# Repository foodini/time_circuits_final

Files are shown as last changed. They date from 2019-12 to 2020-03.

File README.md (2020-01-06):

# Arduino Time Circuits

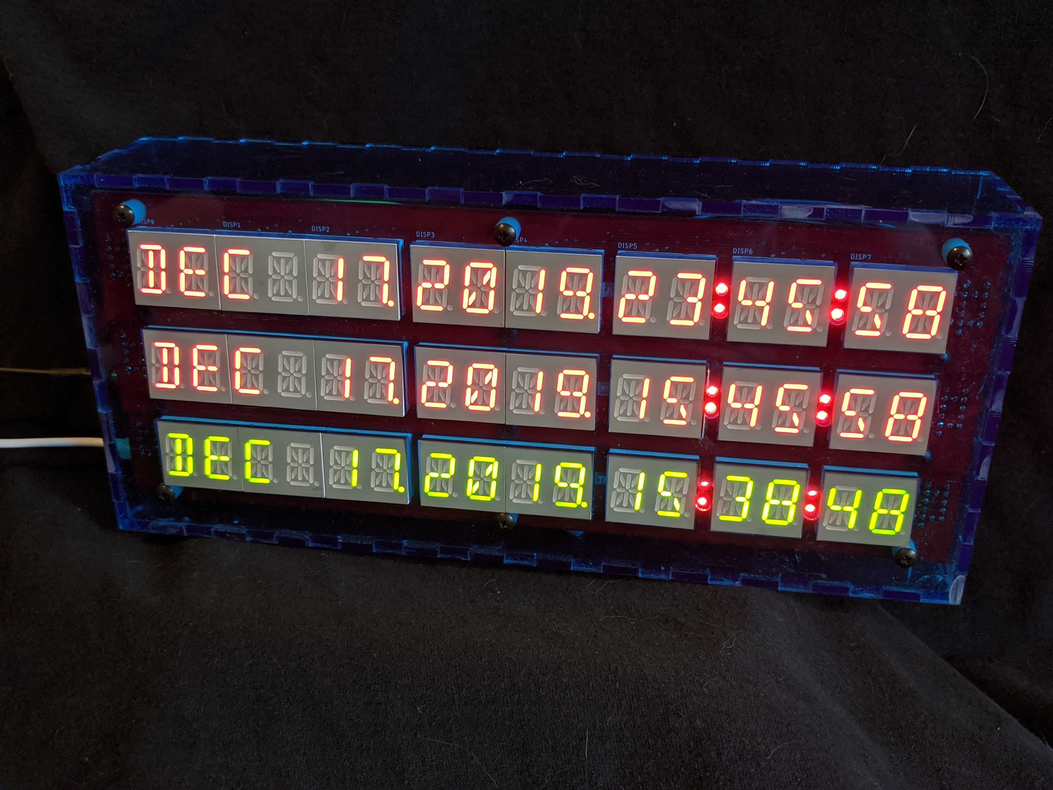
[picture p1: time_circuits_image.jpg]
Time Circuits Image


This is a project I've been working on for.... far too long. There've been [previous iterations]
(https://www.youtube.com/watch?v=cxGm47E_y9M) of this doodad, but [there were issues].
(https://www.youtube.com/watch?v=KKTgsbm41c8)

There was certainly an inspiration from the Back to Future series, but the idea of building a
replica of the device in that series bored me. I like clocks, but I like FUNCTIONAL devices, and
"Where you are, where you're going, and where you've been" isn't very functional to anyone who
hasn't built themselves a real time machine.

What IS useful is a real clock. I frequently work with servers that run on Universal Coordinated
Time (UTC), so having a clock that displays UTC and local time is useful to me. As long as I was
building a two-line clock.... why not three? ("...do it with a little style!") The question of
what to put on the third line languished for a while until it dawned on me what you'd see in a 
clock showing SOLAR time while DRIVING.

Think of it this way: If it takes you ten hours to drive East to the next time zone, it'll be
ELEVEN hours later when you get there. Normally, you just reset your watch when you get there,
but what if we instead had a clock that tracked "Wild West" time. Before time standards, everyone
set their clocks to local noon - they'd use the moment that the sun was highest in the sky as
their standard of time. Why bother? Well, if I'm driving east at about 100kph (at my latitude),
solar time advances by 1.1 times faster than real-time. You can see this difference if you watch
the clock while moving. (Please don't do this if you're the one driving. Duh.)

This clock computes your local solar time every 100ms, taking into account your longitudinal
position, as well as the Earth's position in its orbit. In writing the firmware, I was shocked
to learn that the effect of the orbit on local solar noon varies by something like +- 15 minutes
through the year!
There are still some debug modes languishing in the firmware that should be polished a bit. I'm
sure people will want more features, and I'll do my best to oblige. What I will absolutely NOT
do is make the adjustment for time zones automatic. I did the legwork to make this happen and
came to the conclusion that it simply isn't realistic without giving the clock an SD card and a
way to constantly update its time zone database. To be honest, the largest reason to avoid
this step was because I didn't want to maintain that database. (Time zone definitions change all
the time.) The actual arduino-side processing would have been easy.

## Resources

The project consists of an Arduino .ino file, two Eagle CAD circuit board designs (one for the
displays and one for the Arduino/GPS controller). I'll see if I can work out a way to manage the
Fusion 360 model of the box in GitHub, but in the meantime it's just shared [on Autodesk's
servers].(https://a360.co/2rUt2ZP)

## TODO
- I need to figure out what to do with leap seconds. When there are 61 seconds in a minute, I
  have to handle it properly. At the moment, the clock will display the same time (on the local
  and solar lines) for 2 seconds.
- Since I've gotten the thing boxed up, I've occasionally bumped the settings buttons. This
  causes local time to change by 15 minutes. I think we need to require that you hit the
  mode button to get to the time-change state, where you can alter local time. After n
  seconds, it should return to the main display.
- Make the LED test the last of the display modes.
- Add a histogram that tells you the distribution of inter-sentence reports from the GPS.

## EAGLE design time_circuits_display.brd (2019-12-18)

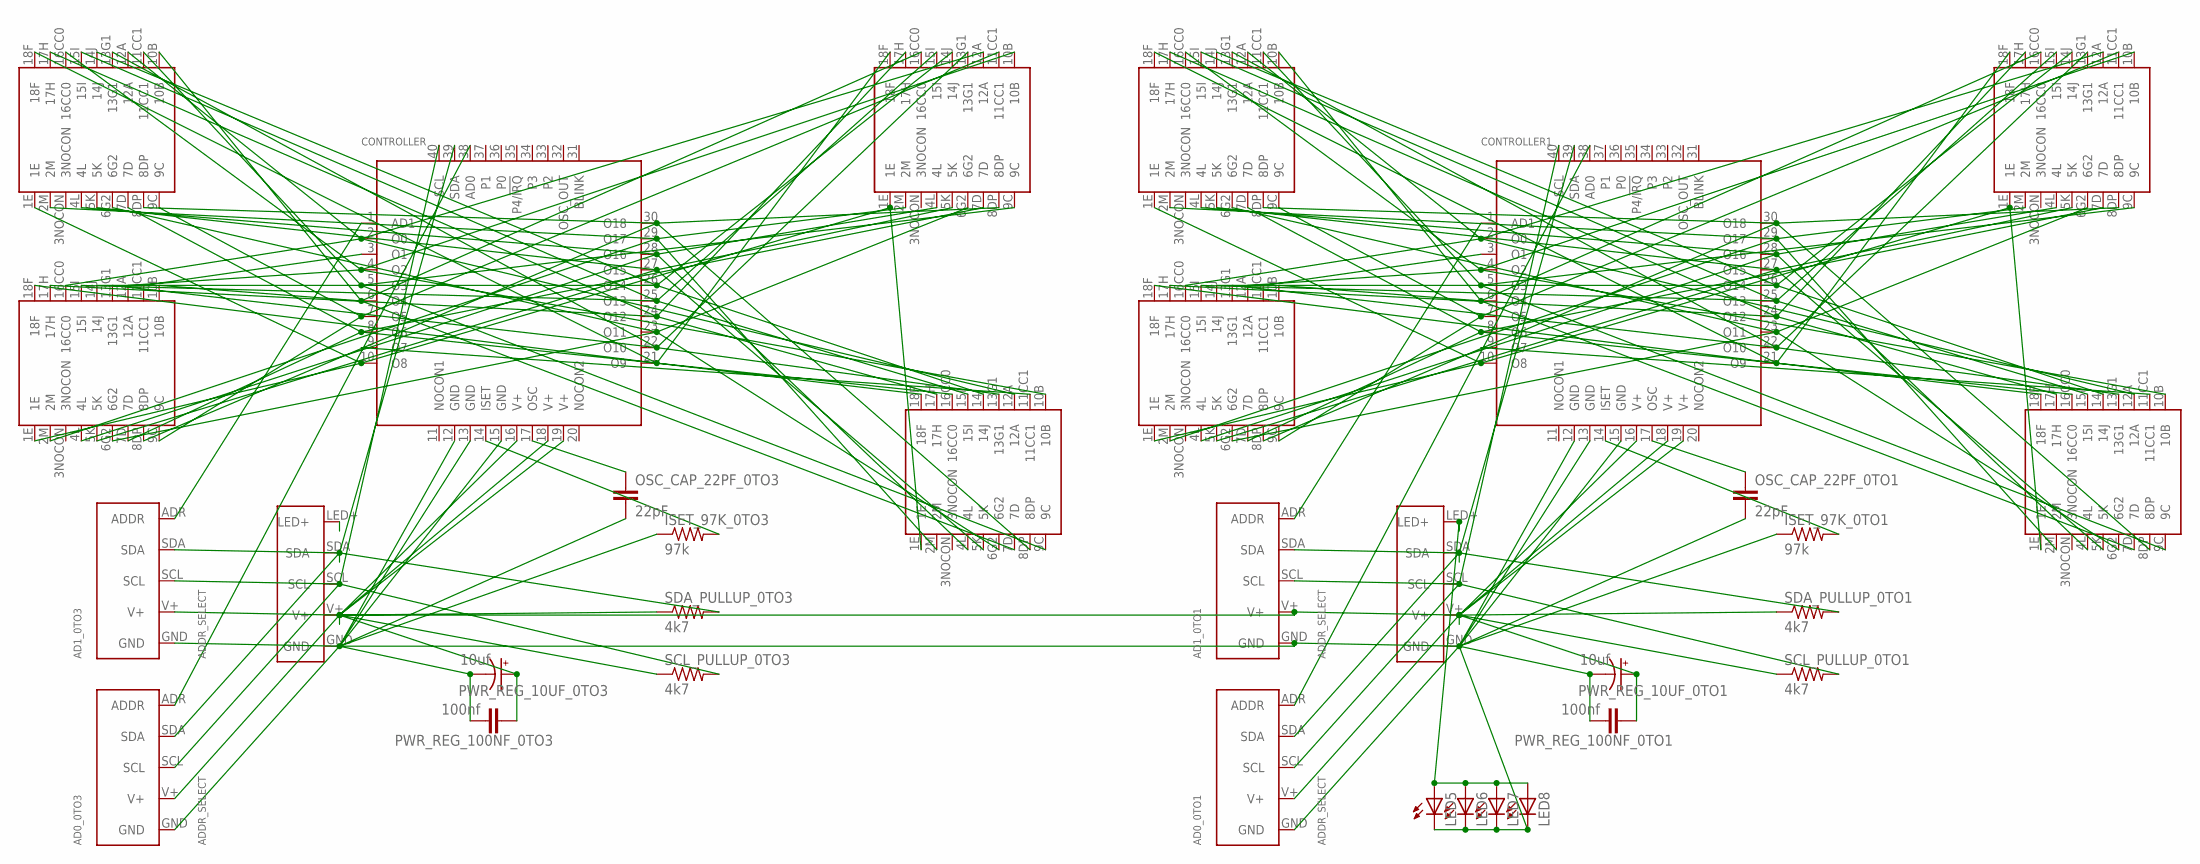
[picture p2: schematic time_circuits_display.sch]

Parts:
AD0_0TO1, AD0_0TO3, AD1_0TO1, AD1_0TO3: ADDR_SELECT
CONTROLLER, CONTROLLER1: MAX6955_TQFN40; TQFN-EP-40
DISP0, DISP1, DISP2, DISP3, DISP4, DISP5, DISP6, DISP7: LTP-3784
GVCD_0TO1, GVCD_0TO3: INTERCONNECTOR4
ISET_97K_0TO1, ISET_97K_0TO3: 97k; 0204/7
LED5, LED6, LED7, LED8: TLLR4400; LED3MM
OSC_CAP_22PF_0TO1, OSC_CAP_22PF_0TO3: 22pF; C025-024X044
PWR_REG_10UF_0TO1, PWR_REG_10UF_0TO3: 10uf; E2-5
PWR_REG_100NF_0TO1, PWR_REG_100NF_0TO3: 100nf; C025-024X044
SCL_PULLUP_0TO1, SCL_PULLUP_0TO3: 4k7; 0204/7
SDA_PULLUP_0TO1, SDA_PULLUP_0TO3: 4k7; 0204/7

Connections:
GND: AD0_0TO1.GND, AD0_0TO3.GND, AD1_0TO1.GND, AD1_0TO3.GND, CONTROLLER.12 (GND), CONTROLLER.13 (GND), CONTROLLER.15 (GND), CONTROLLER1.12 (GND), CONTROLLER1.13 (GND), CONTROLLER1.15 (GND), GVCD_0TO1.GND, GVCD_0TO3.GND, ISET_97K_0TO1.1, ISET_97K_0TO3.1, LED5.K (C), LED6.K (C), LED7.K (C), LED8.K (C), OSC_CAP_22PF_0TO1.2, OSC_CAP_22PF_0TO3.2, PWR_REG_10UF_0TO1.-, PWR_REG_10UF_0TO3.-, PWR_REG_100NF_0TO1.2, PWR_REG_100NF_0TO3.2
unnamed: CONTROLLER.21 (O9), DISP0.18F, DISP1.18F, DISP2.18F, DISP3.18F
unnamed: AD1_0TO3.ADR (ADDR), CONTROLLER.1 (AD1)
unnamed: CONTROLLER.10 (O8), DISP0.1E, DISP1.1E, DISP2.1E, DISP3.1E
unnamed: AD1_0TO1.ADR (ADDR), CONTROLLER1.1 (AD1)
unnamed: CONTROLLER.25 (O13), DISP0.15I, DISP1.15I, DISP2.15I, DISP3.15I
unnamed: AD0_0TO3.ADR (ADDR), CONTROLLER.38 (AD0)
unnamed: CONTROLLER.2 (O0), DISP0.16CC0, DISP1.12A, DISP2.12A, DISP3.12A
unnamed: CONTROLLER.3 (O1), DISP0.11CC1
unnamed: CONTROLLER.4 (O2), DISP0.12A, DISP1.16CC0, DISP2.10B, DISP3.10B
unnamed: CONTROLLER.5 (O3), DISP1.11CC1, DISP2.9C, DISP3.9C
unnamed: CONTROLLER.6 (O4), DISP0.10B, DISP1.10B, DISP2.16CC0, DISP3.7D
unnamed: CONTROLLER.7 (O5), DISP0.9C, DISP1.9C, DISP2.11CC1
unnamed: CONTROLLER.22 (O10), DISP0.13G1, DISP1.13G1, DISP2.13G1, DISP3.13G1
unnamed: CONTROLLER.9 (O7), DISP3.11CC1
unnamed: CONTROLLER.23 (O11), DISP0.6G2, DISP1.6G2, DISP2.6G2, DISP3.6G2
unnamed: CONTROLLER.24 (O12), DISP0.17H, DISP1.17H, DISP2.17H, DISP3.17H
unnamed: CONTROLLER.26 (O14), DISP0.14J, DISP1.14J, DISP2.14J, DISP3.14J
unnamed: CONTROLLER.27 (O15), DISP0.5K, DISP1.5K, DISP2.5K, DISP3.5K
unnamed: CONTROLLER.28 (O16), DISP0.4L, DISP1.4L, DISP2.4L, DISP3.4L
unnamed: CONTROLLER.29 (O17), DISP0.2M, DISP1.2M, DISP2.2M, DISP3.2M
unnamed: CONTROLLER.30 (O18), DISP0.8DP, DISP1.8DP, DISP2.8DP, DISP3.8DP
unnamed: CONTROLLER.17 (OSC), OSC_CAP_22PF_0TO3.1
unnamed: CONTROLLER.14 (ISET), ISET_97K_0TO3.2
unnamed: AD0_0TO3.SCL, AD1_0TO3.SCL, CONTROLLER.40 (SCL), GVCD_0TO3.SCL, SCL_PULLUP_0TO3.2
unnamed: AD0_0TO1.ADR (ADDR), CONTROLLER1.38 (AD0)
unnamed: CONTROLLER.8 (O6), DISP0.7D, DISP1.7D, DISP2.7D, DISP3.16CC0
unnamed: AD0_0TO3.SDA, AD1_0TO3.SDA, CONTROLLER.39 (SDA), GVCD_0TO3.SDA, SDA_PULLUP_0TO3.2
unnamed: CONTROLLER1.2 (O0), DISP4.16CC0, DISP5.12A, DISP6.12A, DISP7.12A
unnamed: CONTROLLER1.3 (O1), DISP4.11CC1
unnamed: CONTROLLER1.4 (O2), DISP4.12A, DISP5.16CC0, DISP6.10B, DISP7.10B
unnamed: CONTROLLER1.5 (O3), DISP5.11CC1, DISP6.9C, DISP7.9C
unnamed: CONTROLLER1.6 (O4), DISP4.10B, DISP5.10B, DISP6.16CC0, DISP7.7D
unnamed: CONTROLLER1.7 (O5), DISP4.9C, DISP5.9C, DISP6.11CC1
unnamed: CONTROLLER1.22 (O10), DISP4.13G1, DISP5.13G1, DISP6.13G1, DISP7.13G1
unnamed: CONTROLLER1.9 (O7), DISP7.11CC1
unnamed: CONTROLLER1.23 (O11), DISP4.6G2, DISP5.6G2, DISP6.6G2, DISP7.6G2
unnamed: CONTROLLER1.24 (O12), DISP4.17H, DISP5.17H, DISP6.17H, DISP7.17H
unnamed: CONTROLLER1.26 (O14), DISP4.14J, DISP5.14J, DISP6.14J, DISP7.14J
unnamed: CONTROLLER1.27 (O15), DISP4.5K, DISP5.5K, DISP6.5K, DISP7.5K
unnamed: CONTROLLER1.28 (O16), DISP4.4L, DISP5.4L, DISP6.4L, DISP7.4L
unnamed: CONTROLLER1.29 (O17), DISP4.2M, DISP5.2M, DISP6.2M, DISP7.2M
unnamed: CONTROLLER1.30 (O18), DISP4.8DP, DISP5.8DP, DISP6.8DP, DISP7.8DP
unnamed: CONTROLLER1.17 (OSC), OSC_CAP_22PF_0TO1.1
unnamed: CONTROLLER1.14 (ISET), ISET_97K_0TO1.2
unnamed: CONTROLLER1.8 (O6), DISP4.7D, DISP5.7D, DISP6.7D, DISP7.16CC0
unnamed: AD0_0TO1.SDA, AD1_0TO1.SDA, CONTROLLER1.39 (SDA), GVCD_0TO1.SDA, SDA_PULLUP_0TO1.2
unnamed: AD0_0TO1.SCL, AD1_0TO1.SCL, CONTROLLER1.40 (SCL), GVCD_0TO1.SCL, SCL_PULLUP_0TO1.2
unnamed: GVCD_0TO1.LED+, LED5.A, LED6.A, LED7.A, LED8.A
unnamed: CONTROLLER1.21 (O9), DISP4.18F, DISP5.18F, DISP6.18F, DISP7.18F
unnamed: CONTROLLER1.10 (O8), DISP4.1E, DISP5.1E, DISP6.1E, DISP7.1E
unnamed: CONTROLLER1.25 (O13), DISP4.15I, DISP5.15I, DISP6.15I, DISP7.15I
VCC: AD0_0TO1.V+, AD0_0TO3.V+, AD1_0TO1.V+, AD1_0TO3.V+, CONTROLLER.16 (V+), CONTROLLER.18 (V+), CONTROLLER.19 (V+), CONTROLLER1.16 (V+), CONTROLLER1.18 (V+), CONTROLLER1.19 (V+), GVCD_0TO1.V+, GVCD_0TO3.V+, PWR_REG_10UF_0TO1.+, PWR_REG_10UF_0TO3.+, PWR_REG_100NF_0TO1.1, PWR_REG_100NF_0TO3.1, SCL_PULLUP_0TO1.1, SCL_PULLUP_0TO3.1, SDA_PULLUP_0TO1.1, SDA_PULLUP_0TO3.1

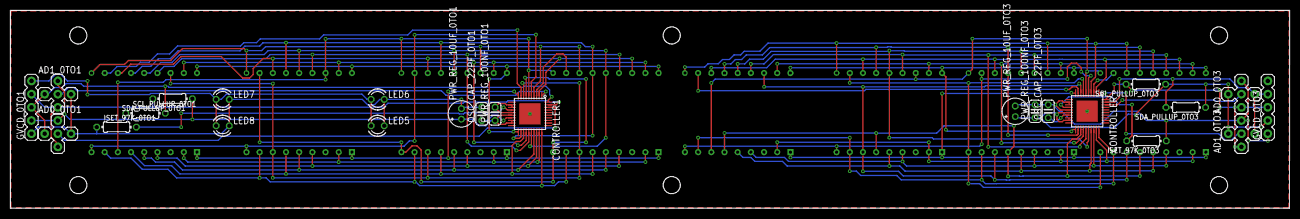
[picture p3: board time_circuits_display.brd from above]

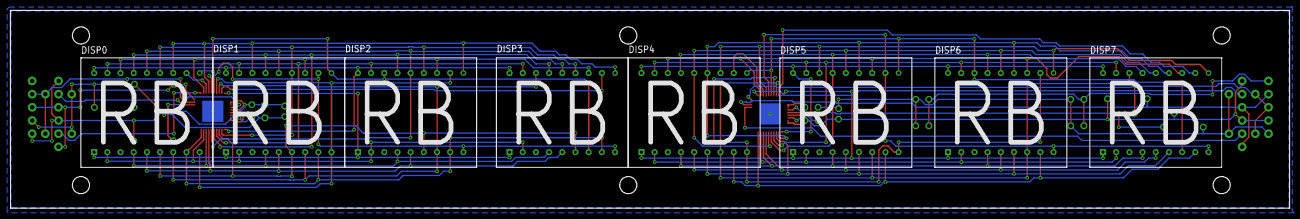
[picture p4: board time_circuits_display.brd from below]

Board: 2 copper layers, 246.4 x 38.1 mm, 32 parts (8 on the bottom side), 53 nets.

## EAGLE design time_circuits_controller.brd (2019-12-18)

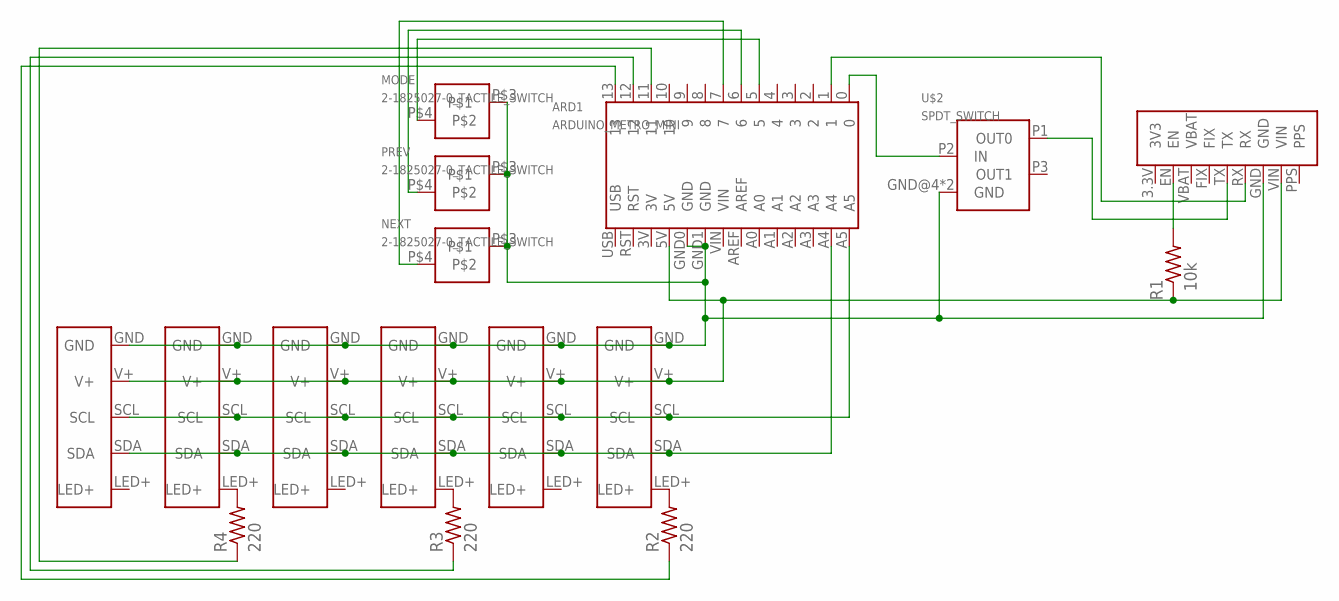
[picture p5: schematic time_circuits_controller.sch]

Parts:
ARD1: ARDUINO_METRO_MINI
MODE: 2-1825027-0_TACTILE_SWITCH
NEXT: 2-1825027-0_TACTILE_SWITCH
OUTPUT_00, OUTPUT_01, OUTPUT_10, OUTPUT_11, OUTPUT_20, OUTPUT_21: INTERCONNECTOR4
PREV: 2-1825027-0_TACTILE_SWITCH
R1: 10k; 0204/7
R2, R3, R4: 220; 0204/7
U$1: GPSBREAKOUTV3
U$2: SPDT_SWITCH

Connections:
5V: ARD1.5V, OUTPUT_00.V+, OUTPUT_01.V+, OUTPUT_10.V+, OUTPUT_11.V+, OUTPUT_20.V+, OUTPUT_21.V+, R1.1, U$1.VIN
GND: ARD1.GND0 (GND), ARD1.GND1 (GND), MODE.P$3, NEXT.P$3, OUTPUT_00.GND, OUTPUT_01.GND, OUTPUT_10.GND, OUTPUT_11.GND, OUTPUT_20.GND, OUTPUT_21.GND, PREV.P$3, U$1.GND, U$2.GND@4 (GND), U$2.GND@5 (GND)
unnamed: R1.2, U$1.EN
unnamed: OUTPUT_21.LED+, R2.2
unnamed: OUTPUT_11.LED+, R3.2
unnamed: ARD1.1, U$1.RX
unnamed: ARD1.5, MODE.P$4
unnamed: ARD1.0, U$2.P2 (IN)
unnamed: ARD1.A5, OUTPUT_00.SCL, OUTPUT_01.SCL, OUTPUT_10.SCL, OUTPUT_11.SCL, OUTPUT_20.SCL, OUTPUT_21.SCL
unnamed: ARD1.A4, OUTPUT_00.SDA, OUTPUT_01.SDA, OUTPUT_10.SDA, OUTPUT_11.SDA, OUTPUT_20.SDA, OUTPUT_21.SDA
unnamed: OUTPUT_01.LED+, R4.2
unnamed: ARD1.11, R4.1
unnamed: ARD1.12, R3.1
unnamed: ARD1.13, R2.1
unnamed: U$1.TX, U$2.P1 (OUT0)
unnamed: ARD1.6, PREV.P$4
unnamed: ARD1.7, NEXT.P$4

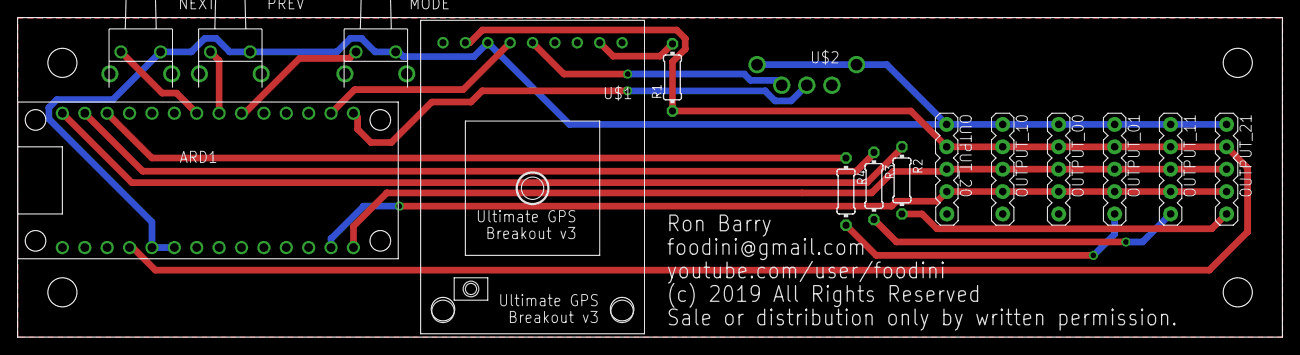
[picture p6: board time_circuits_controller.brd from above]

Board: 2 copper layers, 143.5 x 36.2 mm, 16 parts (0 on the bottom side), 17 nets.

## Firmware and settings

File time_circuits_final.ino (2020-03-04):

#include "Wire.h"

//#include <SoftwareSerial.h>  //Must be here to avoid weird compile error in Adafruit_GPS.h
#include <Adafruit_GPS.h>
#include <EEPROM.h>

#include "tc_datetime.h"
#include "tc_util.h"

/*
 * TODO:
 * 
 *  * There are only 38 actual time zones (https://en.wikipedia.org/wiki/List_of_UTC_time_offsets)
 *  * We have one major problem remaining. The 61st second of leap seconds.
 *  * Break out the EEPROM comms into its own .h/.cpp
 *  * Break out button handling into its own .h/.cpp
 *  * Fix the discontinuity in solar_offset. I wrote it very late at night and never got back.
 *  * Standardize commenting style.
 */

/*
      AD1 AD0 A6 A5 A4 A3 A2 A1 A0
  0   GND GND 1  1  0  0  0  0  0
  1   GND V+  1  1  0  0  0  0  1
  2   GND SDA 1  1  0  0  0  1  0
  3   GND SCL 1  1  0  0  0  1  1
  4   V+  GND 1  1  0  0  1  0  0
  5   V+  V+  1  1  0  0  1  0  1
  6   V+  SDA 1  1  0  0  1  1  0
  7   V+  SCL 1  1  0  0  1  1  1
  8   SDA GND 1  1  0  1  0  0  0
  9   SDA V+  1  1  0  1  0  0  1
  10  SDA SDA 1  1  0  1  0  1  0
  11  SDA SCL 1  1  0  1  0  1  1
  12  SCL GND 1  1  0  1  1  0  0
  13  SCL V+  1  1  0  1  1  0  1
  14  SCL SDA 1  1  0  1  1  1  0
  15  SCL SCL 1  1  0  1  1  1  1
*/

class Stopwatch {
  private:
    unsigned long m_start_time;
  public:
    Stopwatch() {
      reset();
    }
    void reset() {
      m_start_time = millis();
    }
    unsigned long elapsed() {
      unsigned long cur_time = millis();
      if (cur_time < m_start_time)
        return 4294967295 - m_start_time + cur_time;
      return cur_time - m_start_time;
    }
};

#define NUM_ROWS 3
uint8_t addresses[NUM_ROWS][2] = {
  {B1100000, B1100001},
  {B1100010, B1100011},
  {B1100100, B1100101},
};

Adafruit_GPS GPS(&Serial);
bool connected_to_gps = false;
SIGNAL(TIMER0_COMPA_vect) {
  char c = GPS.read();
}

// The vast majority of the time, I populate the frame buffer and immediately push its state
// out to the display. It's nice to have it, though, because it means that I can write stuff
// to it during debugging and expect it to display on the next push.
char display_strs[NUM_ROWS][16];

// display states;
//   0  standard time display
//   1  GPS location display
//   2  debug stats
//   3  Turn on all LEDs
//   4  # loop() runs, time since last GPS fix, millis(), millis()@last GPS receipt
//   5  debugging info for lost GPS comms
//   6  EEPROM state for local timezone offset storage.
uint8_t display_state;

// Button states. Each "down" state is set while the button is held down. "pressed"
// is only true when the button went down on the last refresh.
bool prev_down = false;
bool prev_pressed = false;
bool next_down = false;
bool next_pressed = false;
bool mode_down = false;
bool mode_pressed = false;

uint32_t loops = 0;
uint8_t current_tz_offset;

uint32_t sentences_received = 0;
uint32_t first_sentence_timestamp_ms = 0;

// Pressing the "mode" button switches between a number of displays.
const int8_t NUM_MODES = 6;
bool recent_tz_change = false;

Stopwatch tz_change_timer;

int writeMAX6955(char command, char data, uint8_t address)
{
  Wire.beginTransmission(address);
  Wire.write(command);
  Wire.write(data);
  int error = Wire.endTransmission();
}

#define max6955_reg_decodeMode      0x01
#define max6955_reg_globalIntensity 0x02
#define max6955_reg_scanLimit       0x03
#define max6955_reg_configuration   0x04
#define max6955_reg_displayTest     0x07
#define max6955_reg_digitType       0x0C
void initMAX6955()
{
  Wire.begin();
  for (int row = 0; row < NUM_ROWS; row++) {
    for (int controller = 0; controller < 2; controller++) {
      uint8_t address = addresses[row][controller];
      // ascii decoding for all digits;
      writeMAX6955(max6955_reg_decodeMode, 0xFF, address);
      // brightness: 0x00 =  1/16 (min on)  2.5 mA/seg;
      // 0x0F = 15/16 (max on) 37.5 mA/segment
      writeMAX6955(max6955_reg_globalIntensity, 0x0f, address);
      // active displays: 0x07 -> all;
      writeMAX6955(max6955_reg_scanLimit, 0x07, address);
      // set normal operation;
      writeMAX6955(max6955_reg_configuration, 0x01, address);
      // segments/display: 0xFF=14-seg; 0=16 or 7-seg;
      writeMAX6955(max6955_reg_digitType, 0xff, address);
      // display test on;
      writeMAX6955(max6955_reg_displayTest, 0x01, address);
    }
  }
  delay(1000);
  for (int row = 0; row < NUM_ROWS; row++) {
    for (int controller = 0; controller < 2; controller++) {
      uint8_t address = addresses[row][controller];
      // display test off;
      writeMAX6955(max6955_reg_displayTest, 0x00, address);
      memset(display_strs[0], ' ', 8);
      writeDisplay(display_strs[0], address);
    }
  }
}

void writeDisplay(char* msg, uint8_t address)
{
  for (int i = 0; i < 8; i++)
  {
    writeMAX6955(0x20 + i, msg[i], address);
  }
}

void writeRow(uint8_t row, char * write_str) {
  writeDisplay(write_str, addresses[row][0]);
  writeDisplay(write_str + 8, addresses[row][1]);
}

/*
void writeChar(byte pos, char letter, boolean dotLit, uint8_t address)
{
  writeMAX6955(0x20 + pos, (dotLit ? 0x80 : 0) | letter, address);
}
*/

bool receive_and_parse() {
  if (GPS.newNMEAreceived()) {
    connected_to_gps = true;
    GPS.parse(GPS.lastNMEA());
    return true;
  }
  return false;
}

void stall(int t, char c0, char c1, uint8_t row) {
  int frac = (t + 31) / 32;
  Stopwatch sw;
  char chars[2] = {c0, c1};
  for(int c = 0; c < 2; c++) {
    for(int i = 0; i < 16; i++) {
      sw.reset();
      while (sw.elapsed() < frac) {
        receive_and_parse();
      }
      display_strs[row][i] = chars[c];
      writeRow(row, display_strs[row]);
    }
  }
}

// strcpy, but no '\0' is written to the destination.
void initGPS() {
  OCR0A = 0xAF;
  TIMSK0 |= _BV(OCIE0A);

  // Give the GPS a few milliseconds to start up, in case it's slower than the arduino.
  bare_strcpy(display_strs[0], (char *)"Flux Cap Fluxing");
  writeRow(0, display_strs[0]);
  stall(500, '-', ' ', 1);

  // The GPS receiver defaults to 9600. We want to run it faster, but have to start at 9600
  // to tell it so.
  Serial.begin(9600);
  memset(display_strs[0]+10, ' ', 6);
  bare_strcpy(display_strs[0], (char *)" 9600 baud");
  writeRow(0, display_strs[0]);
  stall(1000, '-',  ' ', 1);

  GPS.sendCommand(PMTK_SET_BAUD_57600);
  memset(display_strs[0]+10, ' ', 6);
  bare_strcpy(display_strs[0], (char *)"57600 baud");
  writeRow(0, display_strs[0]);
  stall(1000, '-',  ' ', 1);

  memset(display_strs[0]+10, ' ', 6);
  bare_strcpy(display_strs[0], (char *)"wait 4 fix");
  writeRow(0, display_strs[0]);
  while(!connected_to_gps || !GPS.fix) {
    Serial.begin(57600);
    if(connected_to_gps) {
      bare_strcpy(display_strs[2], (char *)"Connected to GPS");
      writeRow(2, display_strs[2]);     
    } else if(millis() > 10.0) {
      bare_strcpy(display_strs[2], (char *)"Rear switch on? ");
      writeRow(2, display_strs[2]);
    }
    stall(500, '=',  ' ', 1);
    GPS.sendCommand(PMTK_SET_BAUD_57600);
    GPS.sendCommand(PMTK_SET_NMEA_OUTPUT_RMCONLY);
    GPS.sendCommand(PMTK_SET_NMEA_UPDATE_10HZ);
    stall(2000, '-',  ' ', 1);
  }
}
const uint8_t magic = 0x88;
uint8_t get_eeprom_tz_offset() {
  //Magic number check:
  if(EEPROM.read(510) == magic && EEPROM.read(511) == magic) {
    uint8_t addr = EEPROM.read(509);
    return(EEPROM.read(addr+1)); 
  } else {
    EEPROM.write(510, magic);
    EEPROM.write(511, magic);
    EEPROM.write(509, 0);     //offset to current tz info
    EEPROM.write(0, 0);       //zeroth write to this address pair.
    // This'll provide a rough guess as to which time zone the user is in, based on their longitude.
    uint8_t tz_offset = map(GPS.longitudeDegrees, -180.0, 180.0, 0, 97);
    // round to the nearest hour, with some bias for the high probability that they're on DST.
    tz_offset = ((tz_offset + 5)/4)*4;
    EEPROM.write(1, tz_offset);
    return tz_offset;
  }
}

// Spread the writes across 256 bytes of eeprom.
void set_eeprom_tz_offset(uint8_t offset) {
  uint8_t addr = EEPROM.read(509);
  uint8_t write_count = EEPROM.read(addr);
  if(write_count == 0xff) {
    addr = (addr + 2) % 256;
  }
  EEPROM.write(addr, write_count + 1);
  EEPROM.write(addr+1, offset);
}

// I understand this formula to be accurate to within 15s.
float solar_offset(const Datetime& current_utc) {
  float n;
  float days_in_year = 365.0;
  switch (current_utc.month) {
    case  1: n =   0; break;
    case  2: n =   31; break;
    case  3: n =   59; break;
    case  4: n =   90; break;
    case  5: n =   120; break;
    case  6: n =   151; break;
    case  7: n =   181; break;
    case  8: n =   212; break;
    case  9: n =   243; break;
    case  10: n =   273; break;
    case  11: n =   304; break;
    case  12: n =   334; break;
  }
  if (current_utc.month > 2 && !current_utc.leap_year()) {
    n += 1;
    days_in_year += 1;
  }
  n += current_utc.day;
  n += current_utc.hour / 24.0;
  n += current_utc.minute / (24.0 * 60.0);
  n += current_utc.seconds / (24.0 * 60.0 * 60.0);
  n += current_utc.milliseconds / (24.0 * 60.0 * 60.0 * 1000.0);
  //
  // DISCONTINUITY! Leap years will have a stutter point. (it's 2:15am. figure it out.)
  //
  float d = 2.0 * 3.141592653 * (n - 81.0) / days_in_year;
  return 9.873 * sin(2 * d) - 7.655 * sin(d + 1.374);
}

bool make_solar_time(const Datetime& current_utc, char * str) {
  // The GPS.longitude_fixed is in tenmillionths of a degree. To scale our longitude to a float:
  // GPS.longitude_fixed / 180.0     Scale to the 0.0-1.0 range
  //                     * 12        hours per hemisphere
  //                     * 3600      seconds per hour
  //                     * 1000      milliseconds per second
  //                     / 10^7      removed the fixed-point scaling.
  //                     = * 0.024   Do the divide first to avoid overflow
  int32_t displacement = GPS.longitude_fixed / 1000;
  displacement *= 24;
  // displacement is now the distance - in milliseconds - from 0 longitude

  // Earth's axial tilt and the eccentricity of its orbit cause the difference between solar noon
  // and mean noon to move around by as much as +- 13 minutes. Get the number of milliseconds of
  // difference between mean solar time and solar time:
  displacement += solar_offset(current_utc) * 60 * 1000;

  Datetime solar_time(current_utc);
  solar_time.milliseconds += displacement;
  solar_time.normalize();
  solar_time.make_time_str(str);
  return solar_time.milliseconds < 500;
}

// TODO: Get off of the float latitude and longitude and switch to using the fixed-point
//       version? I do use fixed, elsewhere.
float degmins_to_decimal(float degmins) {
  //Adafruit_GPS stores latitude and longitude in a format where everything to the left of
  //the decimal point is (degrees * 100) + minutes. Right of the decimal point is fraction
  //of minutes. We have to unpack this format to get an old-fashioned float. They probably
  //did it this way for the sake of getting the best precision out of a float that they
  //could.
  degmins /= 100.0;
  int degs = (int)degmins;
  float fract = degmins - degs;
  return degs + fract * 100.0 / 60.0;
}

void set_colons(int8_t pin, bool state) {
  if (state)
    digitalWrite(pin, HIGH);
  else
    digitalWrite(pin, LOW);
}

// For whatever tz offset the user has selected, we've stored it as a value
// between 0 and 97, inclusive. Convert it to an hour/minute offset. Note that
// a negative offset will return negative minutes. This is useful where we add
// these offsets to GPS hours and minutes before normalizing them.
void get_tz_offset(int8_t * hours, int8_t * minutes) {
  int8_t tz_offset_in_qtr_hours = int8_t(current_tz_offset) - 48;
  *hours = tz_offset_in_qtr_hours / 4;
  *minutes = (tz_offset_in_qtr_hours % 4) * 15;
}

// A low-memory way to print ints right-justified. (sprintf aint cheap in terms of
// CPU or memory. Just including it in your code is a huge progmem hit.)
// TODO: allow caller to choose between space-preamble and 0-preamble. You can't just change
//       the memset to do it. Negatives would come out "00-5" instead of "-005".
void rjust(int32_t val, char * buf, int width) {
  memset(buf, ' ', width);
  char tmp[12];
  ltoa(val, tmp, 10);
  int len = strlen(tmp);
  bare_strcpy(buf + width - len, tmp);
}

// Given the current state of the timezone offset, print it to a display row. For the moment,
// it will only print where the LED colons neatly line up (the last 7 digits) so you ge
// "-12:15:00".
void draw_tz_offset(int8_t row) {
  int8_t time_zone_offset_hours, time_zone_offset_minutes;
  get_tz_offset(&time_zone_offset_hours, &time_zone_offset_minutes);
  rjust(time_zone_offset_hours, display_strs[row]+9, 3);
  rjust(abs(time_zone_offset_minutes), display_strs[row]+12, 2);
  // TODO: have rjust take a bool that fills leading zeroes
  if(time_zone_offset_minutes == 0)
    display_strs[row][12] = '0';
  memset(display_strs[row]+14, '0', 2);
  if(time_zone_offset_hours == 0 && time_zone_offset_minutes < 0)
    display_strs[row][10] = '-';
  set_colons(11 + row, GPS.milliseconds < 500);
}

// The ftoa() stdlib function generates a decimal point as a character, e.g., "12.345".
// We don't have to waste a digit to print the column - we simply set the high bit of
// the charcter preceding the decimal point and the DP will light on that display.
// I can't get rid of the temp buffer and render the temp string in-place because the temp string
// is two characters (a '.' and a '\0') longer than the output. 
void ftoa_msb_decimal(float f, char * buf, int int_chars, int frac_chars) {
  char tmpbuf[18];
  char * tmpbufptr = tmpbuf;
  //render the float to a temporary buffer:
  dtostrf(f, int_chars + frac_chars + 1,  frac_chars, tmpbuf);
  while (*tmpbufptr) {
    if (*tmpbufptr == '.') {
      *(buf - 1) |= 0x80;
      tmpbufptr++;
    } else {
      *buf = *tmpbufptr;
      buf++;
      tmpbufptr++;
    }
  }
}

void setup()
{
#ifdef RUN_TESTS
  Serial.begin(19200);
  Datetime::run_tests();
  Serial.end();
  while(1);
#endif
  initMAX6955();

  initGPS();
  pinMode(11, OUTPUT);
  pinMode(12, OUTPUT);
  pinMode(13, OUTPUT);
  pinMode(5, INPUT_PULLUP);
  pinMode(6, INPUT_PULLUP);
  pinMode(7, INPUT_PULLUP);
  display_state = 0;

  current_tz_offset = get_eeprom_tz_offset();

}

void update_button(bool * down, bool * pressed, int pin) {
  *pressed = false;
  if (!digitalRead(pin)) { // if the button is down
    if (!(*down)) { // if it was up
      *pressed = true;
    }
    *down = true;
  } else {
    *down = false;
  }
}

Stopwatch button_repeat_timer;
void update_buttons(const Datetime& current_utc, bool gps_out) {
  bool hold_time_elapsed = false;
  update_button(&prev_down, &prev_pressed, 7);
  update_button(&next_down, &next_pressed, 6);
  update_button(&mode_down, &mode_pressed, 5);

  if(mode_pressed || prev_pressed || next_pressed) {
    button_repeat_timer.reset();
  } else if(button_repeat_timer.elapsed() > 200) {
    button_repeat_timer.reset();
    hold_time_elapsed = true;
  }
  if(mode_pressed || (hold_time_elapsed && mode_down)) {
    display_state = (display_state + 1) % NUM_MODES;
    draw_display_state(current_utc, gps_out);
  }
  if(display_state == 0) {
    if(prev_pressed || (hold_time_elapsed && prev_down)) {
      current_tz_offset = (current_tz_offset + 96) % 97;
      draw_display_state(current_utc, gps_out);
    }
    if(next_pressed || (hold_time_elapsed && next_down)) {
      current_tz_offset = (current_tz_offset + 1) % 97;
      draw_display_state(current_utc, gps_out);
    }
  }
}

void draw_time_strings(const Datetime & current_utc) {
  set_colons(11, current_utc.milliseconds % 1000 < 500);
  set_colons(12, current_utc.milliseconds % 1000 < 500);
  current_utc.make_time_str(display_strs[0]);

  Datetime current_local(current_utc);
  int8_t time_zone_offset_hours, time_zone_offset_minutes;
  get_tz_offset(&time_zone_offset_hours, &time_zone_offset_minutes);
  current_local.hour += time_zone_offset_hours;
  current_local.minute += time_zone_offset_minutes;
  current_local.normalize();
  
  current_local.make_time_str(display_strs[1]);

  display_strs[0][5] |= 0x80;
  display_strs[0][9] |= 0x80;
  display_strs[1][5] |= 0x80;
  display_strs[1][9] |= 0x80;

  if(recent_tz_change) {
    memset(display_strs[2], ' ', 8);
    bare_strcpy(display_strs[2]+6, (char *)"UTC");
    draw_tz_offset(2);
  } else {
    bool solar_led_state = make_solar_time(current_utc, display_strs[2]);
    set_colons(13, solar_led_state);
    display_strs[2][5] |= 0x80;
    display_strs[2][9] |= 0x80;
  }
}

void draw_location_string(float latlon, int row, char latlonchar) {
  memset(display_strs[row], ' ', 16);
#ifdef FILMING
  ftoa_msb_decimal(123.456789, display_strs[row] + 3, 3, 7);
#else
  ftoa_msb_decimal(degmins_to_decimal(latlon), display_strs[row] + 3, 3, 7);
#endif
  display_strs[row][5] |= 0x80;
  display_strs[row][13] = '`';
  display_strs[row][15] = latlonchar;
}

void draw_location_strings(const Datetime& current_utc) {
  memset(display_strs[0]+8, ' ', 8);
  bare_strcpy(display_strs[0], (char *)"solar dt");
  ftoa_msb_decimal(solar_offset(current_utc), display_strs[0] + 8, 3, 5);
  draw_location_string(GPS.latitude, 1, GPS.lat);
  draw_location_string(GPS.longitude, 2, GPS.lon);
  set_colons(11, false);
  set_colons(12, false);
  set_colons(13, false);
}

//TODO: rename debug methods
void draw_debug0() {
  rjust(loops, display_strs[0], 8);
  ftoa_msb_decimal(GPS.secondsSinceTime(), display_strs[0] + 8, 5, 3);
  rjust(millis(), display_strs[1], 16);
  bare_strcpy(display_strs[1], (char *)"now");
  float rate;
  if(sentences_received == 0)
    rate = 0.0;
  else {
    rate = (float)(millis() - first_sentence_timestamp_ms) / sentences_received;
  }
  ftoa_msb_decimal(rate, display_strs[2]+6, 4, 6);
  bare_strcpy(display_strs[2], (char *)"sntnce");
  set_colons(12, false);
  set_colons(12, false);
}

//TODO: move this back to a sane spot
//I have had processors that didn't tick at 1000 millis() per second, so I need to
//have a dynamic computation of the device's actual rate so we can (sorta) keep time
//when we lose a gps connection.
float arduino_ticks_per_second = 1000.0;

void draw_debug1() {
  set_colons(11, false);
  set_colons(12, false);
  set_colons(13, false);
  memset(display_strs[0], ' ', 24);
  ftoa_msb_decimal(arduino_ticks_per_second, display_strs[2], 4, 4);
}

void draw_debug2() {
  for(int row=0; row<3; row++)
    memset(display_strs[row], ' ', 16);
  bare_strcpy(display_strs[0], (char *)"magic");
  uint8_t data = EEPROM.read(510);
  display_strs[0][6] = data >> 4;
  display_strs[0][7] = data & 0xf;
  data = EEPROM.read(511);
  display_strs[0][8] = data >> 4;
  display_strs[0][9] = data & 0xf;
  display_strs[0][12] = 'A';
  display_strs[0][13] = 'D';
  data = EEPROM.read(509); 
  display_strs[0][14] = data >> 4;
  display_strs[0][15] = data & 0xf;

  bare_strcpy(display_strs[1], (char *)"UTC");
  rjust(current_tz_offset, display_strs[1]+4, 2);
  draw_tz_offset(1);

  bare_strcpy(display_strs[2], (char *)"writes/val");
  rjust(EEPROM.read(data), display_strs[2]+10, 2);
  rjust(EEPROM.read(data+1), display_strs[2]+14, 2);
}

void draw_xmas_tree() {
  for (int row = 0; row < 3; row++) {
    for (int col = 0; col < 16; col++) {
      display_strs[row][col] = B10100011;  // Everything on.st
    }
  }
  set_colons(11, false);
  set_colons(12, false);
  set_colons(13, false);
}

void draw_display_state(const Datetime& current_utc, bool gps_out) {
  bool time_draw_done = false;

  switch(display_state) {
    case 0:  draw_time_strings(current_utc);      break;
    case 1:  draw_location_strings(current_utc);  break;
    case 2:  draw_xmas_tree();                    break;
    case 3:  draw_debug0();                       break;
    case 4:  draw_debug1();                       break;
    case 5:  draw_debug2();                       break;
  }

  if(gps_out) {
    //Turn on the indicator whenever the GPS is out.
    display_strs[0][0] |= 0x80;
    //...but have it start blinking if it's a long outage:
    if(GPS.secondsSinceTime() > 1.0 && (millis() % 500) > 250) {
      display_strs[0][0] ^= 0x80;
    }
  }

  // TODO: do the blit only when something has changed?
  writeRow(0, display_strs[0]);
  writeRow(1, display_strs[1]);
  writeRow(2, display_strs[2]);

}

Stopwatch millis_timer;
bool gps_out = false;

void loop() {
  loops++;

  Datetime current_utc(GPS);
  update_buttons(current_utc, gps_out);

  if(display_state == 0 && (next_down or prev_down)) {
    recent_tz_change = true;
    tz_change_timer.reset();
  }
  if(recent_tz_change && tz_change_timer.elapsed() > 3000) {
    recent_tz_change = false;
    set_eeprom_tz_offset(current_tz_offset);
  }

  if(receive_and_parse()) {
    //uint32_t sentences_received;
    //uint32_t first_sentence_timestamp_ms = 0;
    if(sentences_received == 0)
      first_sentence_timestamp_ms = millis();
    sentences_received++;
  } 
  
  float seconds_since_gps_sentence = GPS.secondsSinceTime();
  if(seconds_since_gps_sentence > 0.250) {
    current_utc.milliseconds += seconds_since_gps_sentence * arduino_ticks_per_second;
    current_utc.normalize();
    gps_out = true;
  } else {
    gps_out = false;
  }

  draw_display_state(current_utc, gps_out);
}

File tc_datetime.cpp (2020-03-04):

#include <Adafruit_GPS.h>
#include "tc_datetime.h"

Datetime::Datetime(const Adafruit_GPS& gps) {
  init_from_adafruit_gps(gps);
}

void Datetime::operator=(const Adafruit_GPS& gps) {
  init_from_adafruit_gps(gps);
}

bool Datetime::operator==(const Datetime& rhs) {
  return (milliseconds == rhs.milliseconds && seconds == rhs.seconds && minute == rhs.minute && 
          hour == rhs.hour && day == rhs.day && month == rhs.month && year == rhs.year);
}

bool Datetime::operator!=(const Datetime& rhs) {
  return !operator==(rhs);
}

void Datetime::init_from_adafruit_gps(const Adafruit_GPS& gps) {
  year = uint16_t(gps.year)+2000;
  month = gps.month;
  day = gps.day;
  hour = gps.hour;
  minute = gps.minute;
  seconds = gps.seconds;
  milliseconds = gps.milliseconds;      
}

char* Datetime::get_month_str(int m) {
  switch (m) {
    case  1: return (char *)"JAN ";
    case  2: return (char *)"FEB ";
    case  3: return (char *)"MAR ";
    case  4: return (char *)"APR ";
    case  5: return (char *)"MAY ";
    case  6: return (char *)"JUN ";
    case  7: return (char *)"JUL ";
    case  8: return (char *)"AUG ";
    case  9: return (char *)"SEP ";
    case 10: return (char *)"OCT ";
    case 11: return (char *)"NOV ";
    case 12: return (char *)"DEC ";
    default: return (char *)"    ";
  }
}

/*
 * Returns whether self's year is a leap year.
 */
bool Datetime::leap_year() {
  if (year % 4 == 0) {
    if (year % 100 == 0) {
      if (year % 400 == 0) {
        return true;
      }
      return false;
    }
    return true;
  }
  return false;
}

/*
 * Pack the Datetime into a character string, fit for display through the LED controller.
 * The format will look something like this:
 * 
 *  "DEC 132020101500"
 * 
 * It ends up being more readable on the LED display, as the presentation is more like:
 * 
 *  "DEC  13 2020 10:15:00"
 */
void Datetime::make_time_str(char* str) {
  bare_strcpy(str, Datetime::get_month_str(month));
  str[3] = ' ';
  // TODO: use a 0-filling rjust for this
  str[4] = '0' + day / 10;
  str[5] = '0' + day % 10;
  itoa(year, str + 6, 10);
  str[10] = '0' + hour / 10;
  str[11] = '0' + hour % 10;
  str[12] = '0' + minute / 10;
  str[13] = '0' + minute % 10;
  str[14] = '0' + seconds / 10;
  str[15] = '0' + seconds % 10;
}

/*
 * You can add or subtract small deltas to/from Datetimes, but to ensure that the result is a
 * valid date and time afterward, call normalize().
 * 
 * WARNING:
 * Don't try to add or subtract more than 24 hours. Bad things may happen at month boundaires - 
 * especially with regard to leap days. 
 */
void Datetime::normalize() {
  if (milliseconds < 0) {
    seconds += (milliseconds/1000) - 1;
    milliseconds = milliseconds % 1000 + 1000;
  }
  // This isn't an else-if case because it's possible milliseconds became exactly 1000 as a result of
  // the if(milliseconds < 0) block.
  if (milliseconds >= 1000) {
    seconds += milliseconds / 1000;
    milliseconds = milliseconds % 1000;
  }

  if (seconds < 0) {
    minute += (seconds/60) - 1;
    seconds = seconds % 60 + 60;
  } 
  if (seconds >= 60) {
    minute += seconds / 60;
    seconds = seconds % 60;
  }

  if (minute < 0) {
    hour += (minute/60) - 1;
    minute = minute % 60 + 60;
  } 
  if (minute >= 60) {
    hour += minute / 60;
    minute = minute % 60;
  }

  if (hour < 0) {
    day += (hour/24) - 1;
    hour = hour % 24 + 24;
  } 
  if (hour >= 24) {
    day += hour / 24;
    hour = hour % 24;
  }

  if (day < 1) {
    switch (month) {
      case 1: case 2: case 4: case 6: case 8: case 9: case 11:
        day = 31; break;
      case 3:
        if (leap_year())
          day = 29;
        else
          day = 28;
        break;
      default:
        day = 30;
    }
    month -= 1;
  } else {
    switch (month) {
      case 1: case 3: case 5: case 7: case 8: case 10: case 12:
        if (day > 31) {
          day = 1;
          month += 1;
        }
        break;
      case 2:
        if (leap_year()) {
          if (day > 29) {
            day = 1;
            month = 3;
          }
        }
        else if (day > 28) {
          day = 1;
          month = 3;
        }      
        break;
      default:
        if (day > 30) {
          day = 1;
          month += 1;
        }
        break;
    }
  }

  if (month < 1) {
    month = 12;
    year -= 1;
  }

  if (month == 13) {
    month = 1;
    year += 1;
  }

  switch (month) {
    //advancing
    case 1: //31 -> 1
    case 3:
    case 5:
    case 7:
    case 8:
    case 10:
    case 12:
      if (day > 31) {
        if (month == 12) {
          year++;
          month = 0;
        }
        day = 1;
        month++;
      }
      break;
    case 2: // 2[89] -> 1
      if ((year % 4 == 0 && day > 29) || (year % 4 && day > 28)) {
        day = 1;
        month = 3;
      }
      break;
    case 4: // 30 -> 1
    case 6:
    case 9:
    case 11:
      if (day > 30) {
        day = 1;
        month ++;
      }
  }

  if (day < 1) {
    switch (month) {
      //retreating
      case 1: //
        day = 31;
        month--;
        year--;
        break;
      case 2: // 1 -> 31
      case 4:
      case 6:
      case 8:
      case 9:
      case 11:
        day = 31;
        month--;
        break;
      case 3: // 1 -> 2[29]
        if (year % 4 == 0)
          day = 29;
        else
          day = 28;
        month = 2;
        break;
      case 5: // 1 -> 30
      case 7:
      case 10:
      case 12:
        day = 30;
        month--;
        break;
    }
  }
}

#ifdef RUN_TESTS

/*
 * For the sake of displaying a failed test's result, this method dumps the Datetime to Serial like:
 * 
 *  "2020.02.29 01:59:59.999"
 *  (YYYY MM DD HH MM SS.SSS)
 */
void Datetime::print() {
  Serial.print(year);
  Serial.print('.');
  if(month < 10)
    Serial.print(0);
  Serial.print(month);
  Serial.print('.');
  if(day < 10)
    Serial.print(0);
  Serial.print(day);
  
  Serial.print(' ');
  if (hour < 10)
    Serial.print(0);
  Serial.print(hour);
  Serial.print(':');
  if (minute < 10)
    Serial.print(0);
  Serial.print(minute);
  Serial.print(':');
  if (seconds < 10)
    Serial.print(0);
  Serial.print(seconds);
  Serial.print('.');
  if (milliseconds < 100) {
    Serial.print(0);
    if (milliseconds < 10) {
      Serial.print(0);
    }
  }
  Serial.print(milliseconds);
}
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

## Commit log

2019-12-11 Add arduino firmware
2019-12-18 Add all the Eagle CAD files - the library, the boards and the schematics.
    [time_circuits_controller.brd, time_circuits_controller.sch, time_circuits_display.brd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]
2020-03-04 Fix the Leap Day bug, break up into multiple files
    [tc_datetime.cpp, time_circuits_final.ino]

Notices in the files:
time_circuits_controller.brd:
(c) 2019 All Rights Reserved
